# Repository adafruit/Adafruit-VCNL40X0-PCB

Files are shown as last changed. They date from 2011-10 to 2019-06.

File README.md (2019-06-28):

## Adafruit VCNL40x0 Breakout PCB

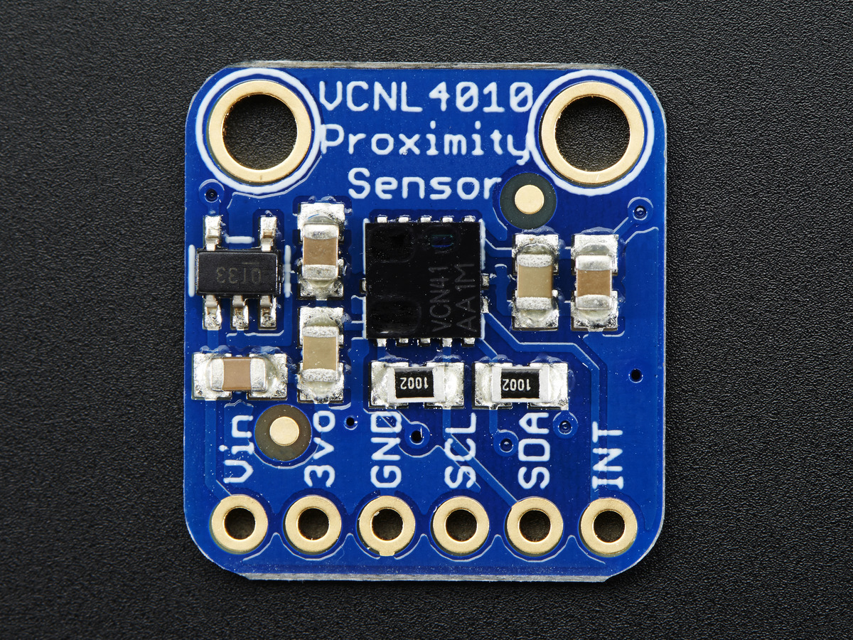
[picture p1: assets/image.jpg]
<a href="http://www.adafruit.com/products/466"><br/>
Click here to purchase one from the Adafruit shop</a>

PCB files for the Adafruit VCNL4000 and VCNL4010 Breakout PCB. Format is EagleCAD schematic and board layout

For more details, check out the product page at

  * https://www.adafruit.com/product/466

### Description

The VCNL4010 sensor is a nice way to add a small-distance proximity sensor to your microcontroller project. For longer distances (in the range of cm, you can use a SHARP IR distance sensor, but those are only good if the object is over 10 cm away. The VCNL4010 is designed for much shorter distances, no more than 200mm (about 7.5") and under our experimentation we found it worked best at distances of about 10-150mm. It would be good for say detecting when a hand moved nearby, or before a robot smacks into a wall. The sensor also has an ambient light sensor built in.

This sensor is easy to use with any microcontroller that has i2c capability. It is 5 volt compliant so you can use it with 3.3V or 5V logic with no risk of damage. There is an onboard 3.3V ultra low dropout regulator so you can power it with 3.3 to 5.0V. However, if you can give it 5.0V that is ideal since the VIN voltage powers the IR LED and the higher the voltage you can give it, the more powerful it is.

As of Sept 23, 2015 we are now shipping this breakout with the updated VCNL4010 - the library has changed and the chip is slightly different in that it now supports interrupts. We also made the board a little more compact. However, the overall proximity functionality is identical.

### License

Adafruit invests time and resources providing this open source design, please support Adafruit and open-source hardware by purchasing products from [Adafruit](https://www.adafruit.com)!

Designed by Limor Fried/Ladyada for Adafruit Industries.

Creative Commons Attribution/Share-Alike, all text above must be included in any redistribution. See license.txt for additional details.

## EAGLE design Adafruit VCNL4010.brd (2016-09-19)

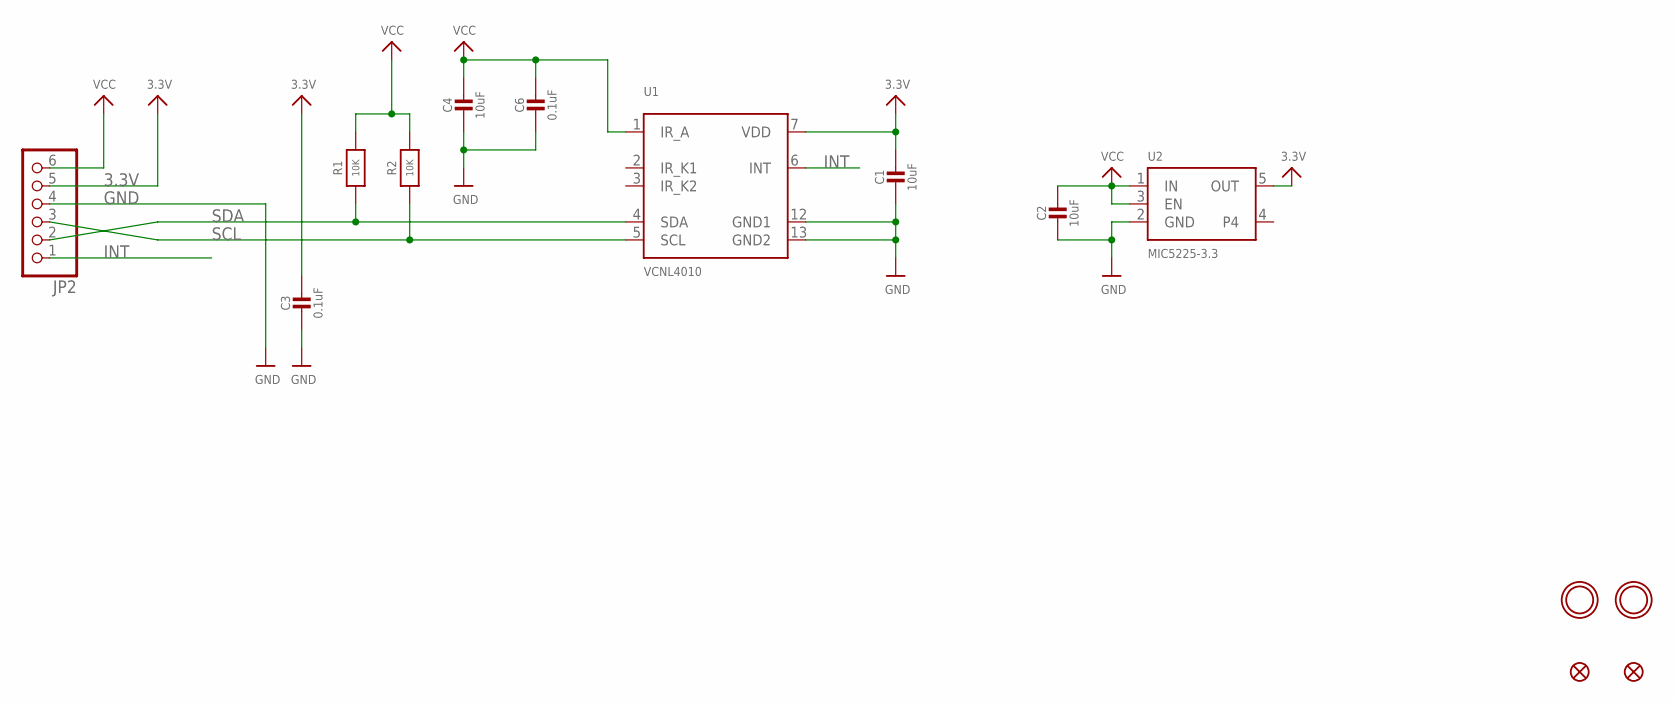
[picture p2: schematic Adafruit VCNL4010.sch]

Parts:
C1, C2, C4: 10uF; 0805-NO
C3, C6: 0.1uF; 0805-NO
JP2: HEADER-1X676MIL; 1X06_ROUND_76
R1, R2: 10K; 0805-NO
U1: VCNL4010
U2: MIC5225-3.3; SOT23-5
U$5, U$6: MOUNTINGHOLE2.5; MOUNTINGHOLE_2.5_PLATED
U$7, U$8: FIDUCIAL""; FIDUCIAL_1MM

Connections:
3.3V: C1.1, C3.1, JP2.5, U1.7 (VDD), U2.5 (OUT)
GND: C1.2, C2.2, C3.2, C4.2, C6.2, JP2.4, U1.12 (GND1), U1.13 (GND2), U2.2 (GND)
INT: JP2.1, U1.6 (INT)
SCL: JP2.3, R2.1, U1.5 (SCL)
SDA: JP2.2, R1.1, U1.4 (SDA)
VIN: C2.1, C4.1, C6.1, JP2.6, R1.2, R2.2, U1.1 (IR_A), U2.1 (IN), U2.3 (EN)

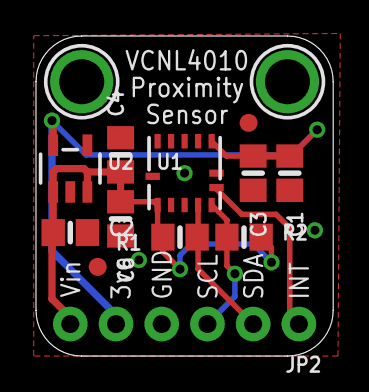
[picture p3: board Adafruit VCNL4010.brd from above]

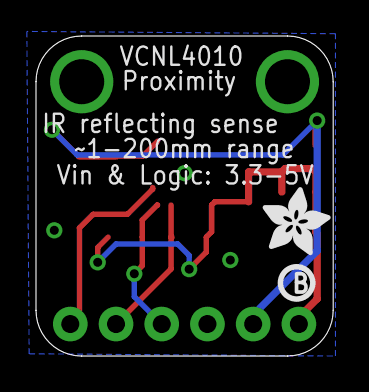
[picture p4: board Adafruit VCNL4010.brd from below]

Board: 2 copper layers, 16.5 x 17.8 mm, 16 parts (2 on the bottom side), 6 nets.

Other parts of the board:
U$13: PCBFEAT-REV-040
U$14: ADAFRUIT_3.5MM

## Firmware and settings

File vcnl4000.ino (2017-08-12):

// Example sketch for talking to the VCNL4000 i2c proximity/light sensor
// Written by Adafruit! Public domain.
// To use: Connect VCC to 3.3-5V (5V is best if it is available), GND to
//         ground, SCL to i2c clock (on classic arduinos, Analog 5), SDA
//         to i2c data (on classic arduinos Analog 4). The 3.3v pin is
//         an ouptut if you need 3.3V
// This sensor is 5V compliant so you can use it with 3.3 or 5V micros

// You can pick one up at the Adafruit shop: www.adafruit.com/products/466



#include <Wire.h>

// the i2c address
#define VCNL4000_ADDRESS 0x13

// commands and constants
#define VCNL4000_COMMAND 0x80
#define VCNL4000_PRODUCTID 0x81
#define VCNL4000_IRLED 0x83
#define VCNL4000_AMBIENTPARAMETER 0x84
#define VCNL4000_AMBIENTDATA 0x85
#define VCNL4000_PROXIMITYDATA 0x87
#define VCNL4000_SIGNALFREQ 0x89
#define VCNL4000_PROXINITYADJUST 0x8A

#define VCNL4000_3M125 0
#define VCNL4000_1M5625 1
#define VCNL4000_781K25 2
#define VCNL4000_390K625 3

#define VCNL4000_MEASUREAMBIENT 0x10
#define VCNL4000_MEASUREPROXIMITY 0x08
#define VCNL4000_AMBIENTREADY 0x40
#define VCNL4000_PROXIMITYREADY 0x20
  
void setup() {
  Serial.begin(9600);

  Serial.println("VCNL");
  Wire.begin();

  uint8_t rev = read8(VCNL4000_PRODUCTID);
  
  if ((rev & 0xF0) != 0x10) {
    Serial.println("Sensor not found :(");
    while (1);
  }
    
  
  write8(VCNL4000_IRLED, 20);        // set to 20 * 10mA = 200mA
  Serial.print("IR LED current = ");
  Serial.print(read8(VCNL4000_IRLED) * 10, DEC);
  Serial.println(" mA");
  
  //write8(VCNL4000_SIGNALFREQ, 3);
  Serial.print("Proximity measurement frequency = ");
  uint8_t freq = read8(VCNL4000_SIGNALFREQ);
  if (freq == VCNL4000_3M125) Serial.println("3.125 MHz");
  if (freq == VCNL4000_1M5625) Serial.println("1.5625 MHz");
  if (freq == VCNL4000_781K25) Serial.println("781.25 KHz");
  if (freq == VCNL4000_390K625) Serial.println("390.625 KHz");
  
  write8(VCNL4000_PROXINITYADJUST, 0x81);
  Serial.print("Proximity adjustment register = ");
  Serial.println(read8(VCNL4000_PROXINITYADJUST), HEX);
  
  // arrange for continuous conversion
  //write8(VCNL4000_AMBIENTPARAMETER, 0x89);

}

uint16_t readProximity() {
  write8(VCNL4000_COMMAND, VCNL4000_MEASUREPROXIMITY);
  while (1) {
    uint8_t result = read8(VCNL4000_COMMAND);
    //Serial.print("Ready = 0x"); Serial.println(result, HEX);
    if (result & VCNL4000_PROXIMITYREADY) {
      return read16(VCNL4000_PROXIMITYDATA);
    }
    delay(1);
  }
}



void loop() {

  // read ambient light!
  write8(VCNL4000_COMMAND, VCNL4000_MEASUREAMBIENT | VCNL4000_MEASUREPROXIMITY);
  
  while (1) {
    uint8_t result = read8(VCNL4000_COMMAND);
    //Serial.print("Ready = 0x"); Serial.println(result, HEX);
    if ((result & VCNL4000_AMBIENTREADY)&&(result & VCNL4000_PROXIMITYREADY)) {

      Serial.print("Ambient = ");
      Serial.print(read16(VCNL4000_AMBIENTDATA));
      Serial.print("\t\tProximity = ");
      Serial.println(read16(VCNL4000_PROXIMITYDATA));
      break;
    }
    delay(10);
  }
  
   delay(100);
 }

// Read 1 byte from the VCNL4000 at 'address'
uint8_t read8(uint8_t address)
{
  uint8_t data;

  Wire.beginTransmission(VCNL4000_ADDRESS);
#if ARDUINO >= 100
  Wire.write(address);
#else
  Wire.send(address);
#endif
  Wire.endTransmission();

  delayMicroseconds(170);  // delay required

  Wire.requestFrom(VCNL4000_ADDRESS, 1);

#if ARDUINO >= 100
  return Wire.read();
#else
  return Wire.receive();
#endif
}


// Read 2 byte from the VCNL4000 at 'address'
uint16_t read16(uint8_t address)
{
  uint16_t data;

  Wire.beginTransmission(VCNL4000_ADDRESS);
#if ARDUINO >= 100
  Wire.write(address);
#else
  Wire.send(address);
#endif
  Wire.endTransmission();

  Wire.requestFrom(VCNL4000_ADDRESS, 2);
#if ARDUINO >= 100
  data = Wire.read();
  data <<= 8;
  data |= Wire.read();
#else
  data = Wire.receive();
  data <<= 8;
  data |= Wire.receive();
#endif
  
  return data;
}

// write 1 byte
void write8(uint8_t address, uint8_t data)
{
  Wire.beginTransmission(VCNL4000_ADDRESS);
#if ARDUINO >= 100
  Wire.write(address);
  Wire.write(data);  
#else
  Wire.send(address);
  Wire.send(data);  
#endif
  Wire.endTransmission();
}

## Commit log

2011-10-11 breakout board files
    [VCNL4000.brd, VCNL4000.sch]
2011-12-03 Arduino 1.0 compliant
2016-09-19 latest version and a readme
    [Adafruit VCNL4010.brd, Adafruit VCNL4010.sch]
